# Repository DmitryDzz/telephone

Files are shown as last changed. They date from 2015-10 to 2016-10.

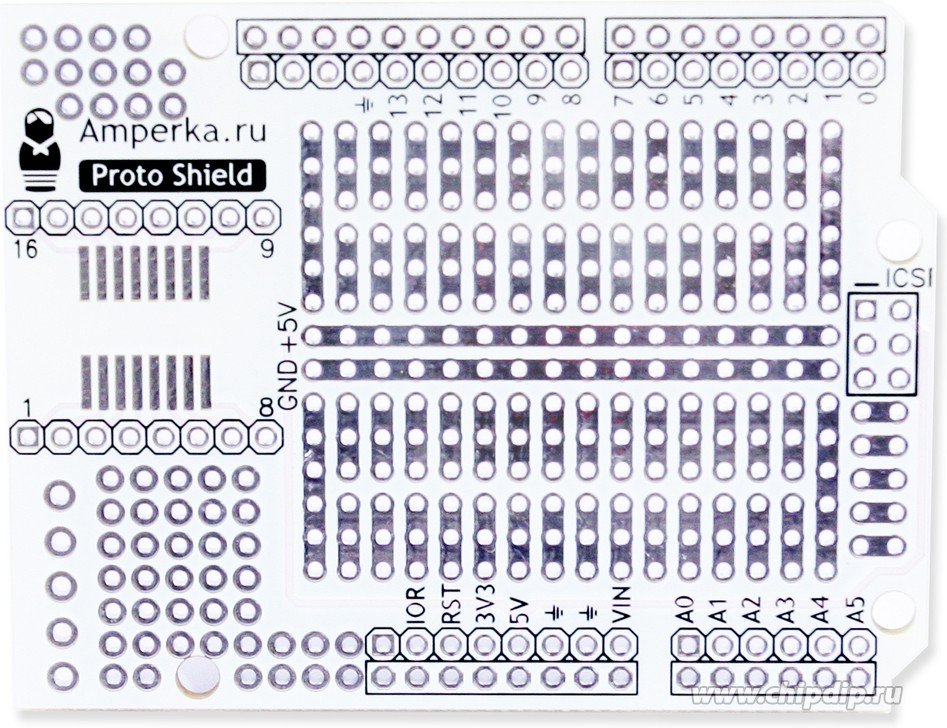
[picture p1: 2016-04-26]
documents/proto-shield.jpg

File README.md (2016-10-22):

# Arduino based cell phone

Arduino based cell phone

Old rotary telephone in modern mobile world. With:
* Arduino UNO controller
* GSM shield
* rechargeable batteries.

To make the phone special I saved its original sound. I mean the sound of its bell set, carbon microphone and rotary dial mechanism.

My detailed instructable [is here](http://www.instructables.com/id/Cell-Phone-With-Bells-AKA-OrPhone/).

Arduino based cell phone

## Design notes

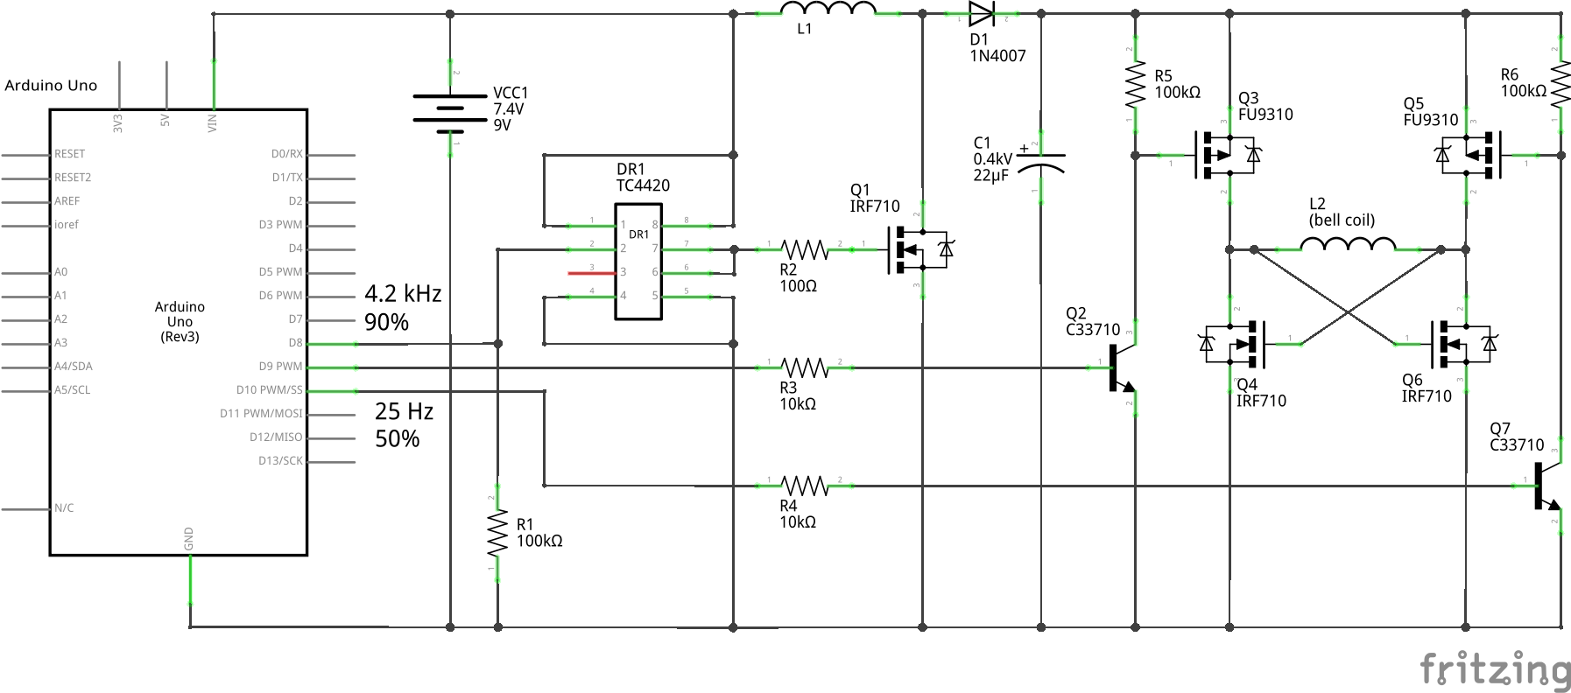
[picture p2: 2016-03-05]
documents/booster/bell-booster-schem.png

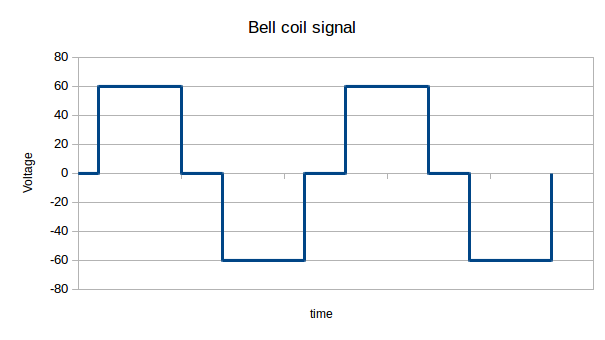
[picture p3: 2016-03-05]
documents/booster/bell-coil-signal.png

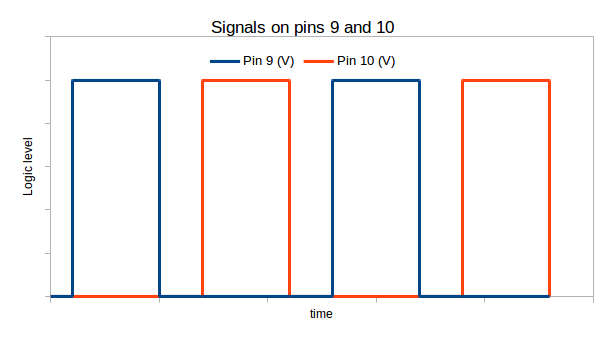
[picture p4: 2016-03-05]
documents/booster/bell-sound-pins-signals.png

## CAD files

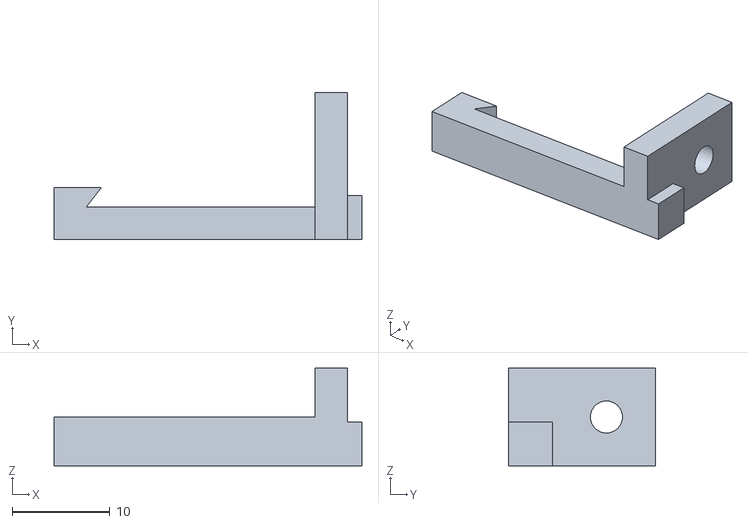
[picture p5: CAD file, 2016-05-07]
3d-printer/antenna-holder.stl
31.5 x 15.0 x 10.0

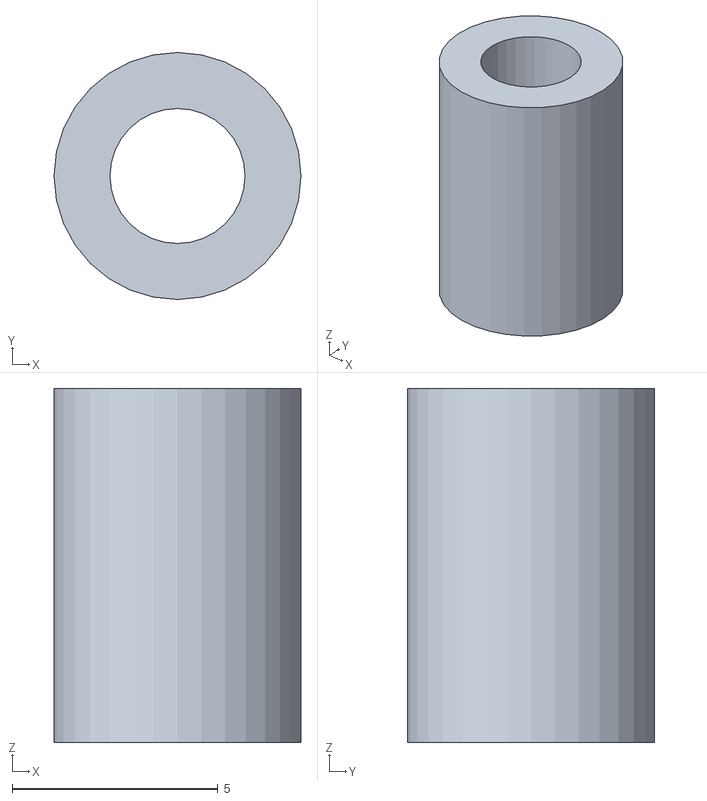
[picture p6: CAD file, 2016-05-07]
3d-printer/arduino-uno-holder.stl
6.00 x 6.00 x 8.60

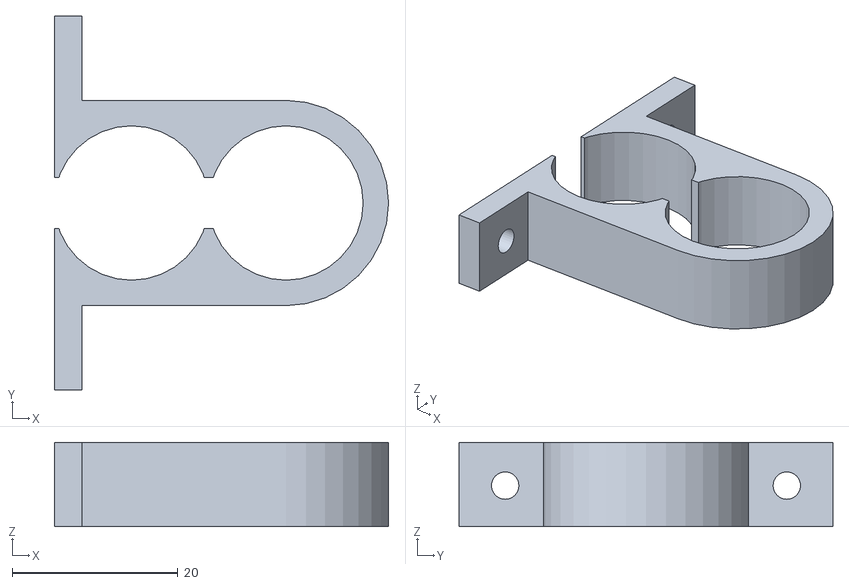
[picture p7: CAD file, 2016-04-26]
3d-printer/battery-18650-holder.stl
40.3 x 45.1 x 10.2

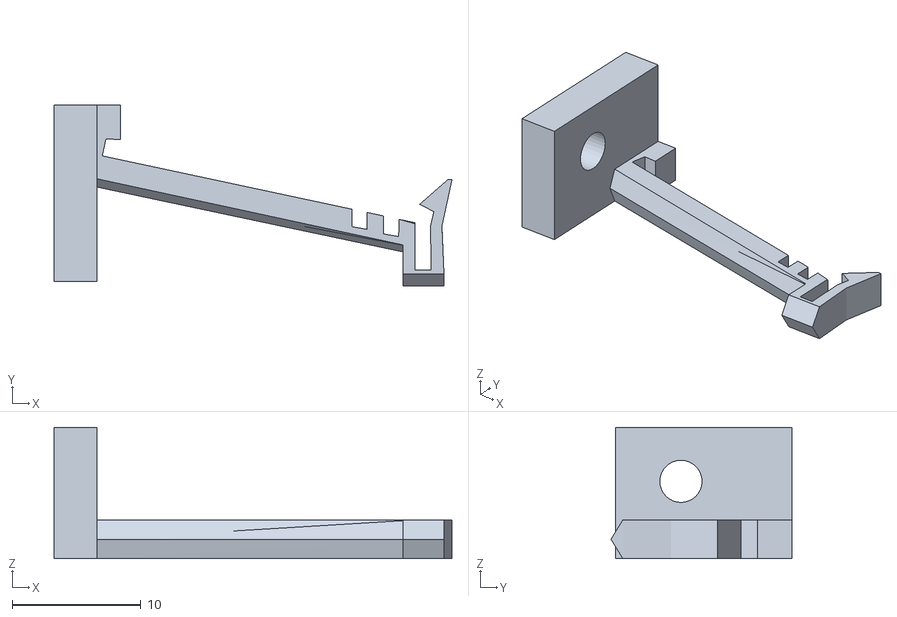
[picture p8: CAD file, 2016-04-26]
3d-printer/charger-holder.stl
30.9 x 14.1 x 10.2

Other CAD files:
3d-printer/antenna-holder.blend
3d-printer/arduino-uno-holder.blend
3d-printer/battery-18650-holder.blend
3d-printer/charger-holder.blend

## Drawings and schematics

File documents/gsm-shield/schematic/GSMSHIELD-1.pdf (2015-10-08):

PWM1 | 35 PWM2 | 36 SDA | 37 SCL | 38 GND | 39 GPIO1/KBR4 | 40 GPIO2/KBR3 | 41 GPIO3/KBR2 | 42 GPIO4/KBR1 | 43 GPIO5/KBR0 | 44 GND | 45 GND | 46 GPIO6/KBC4 | 47 GPIO7/KBC3 | 48 GPIO8/KBC2 | 49 GPIO9/KBC1 | 50 GPIO10 | 51 NETLIGHT

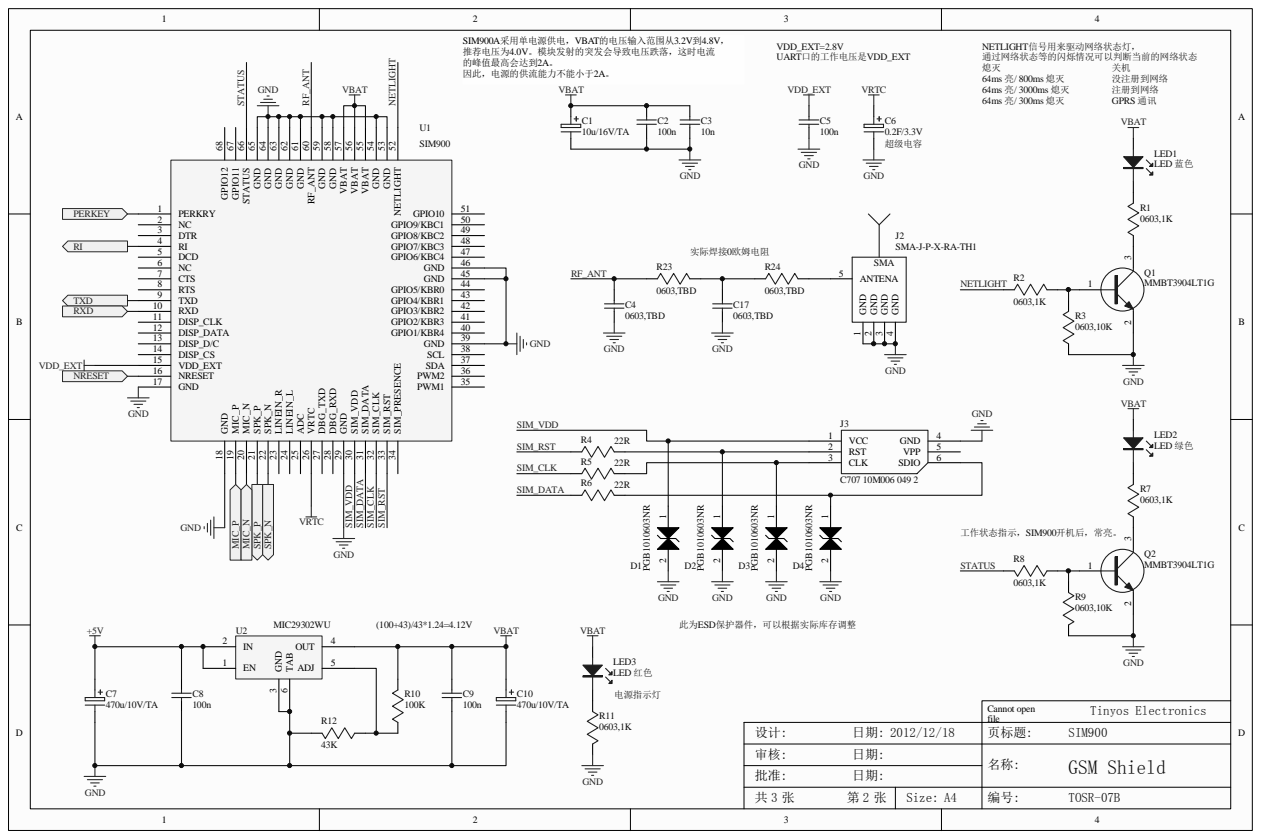
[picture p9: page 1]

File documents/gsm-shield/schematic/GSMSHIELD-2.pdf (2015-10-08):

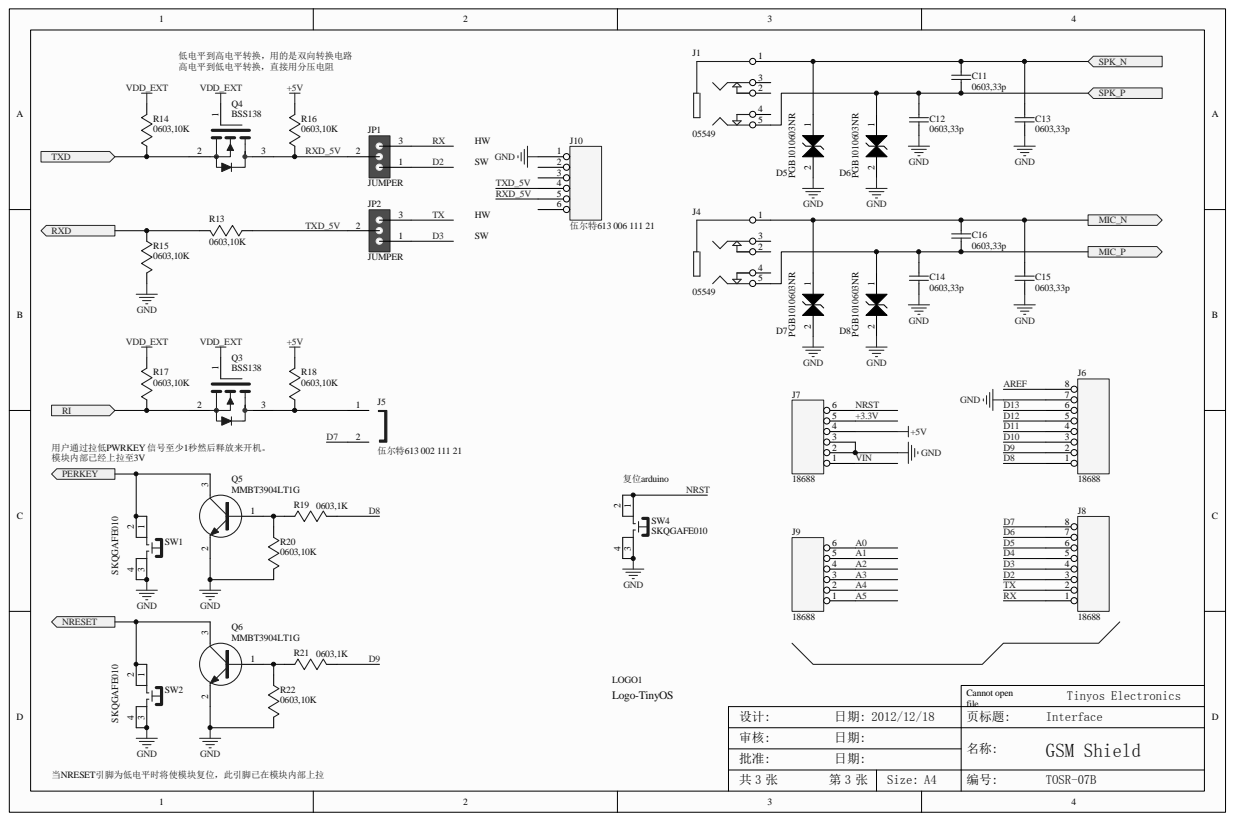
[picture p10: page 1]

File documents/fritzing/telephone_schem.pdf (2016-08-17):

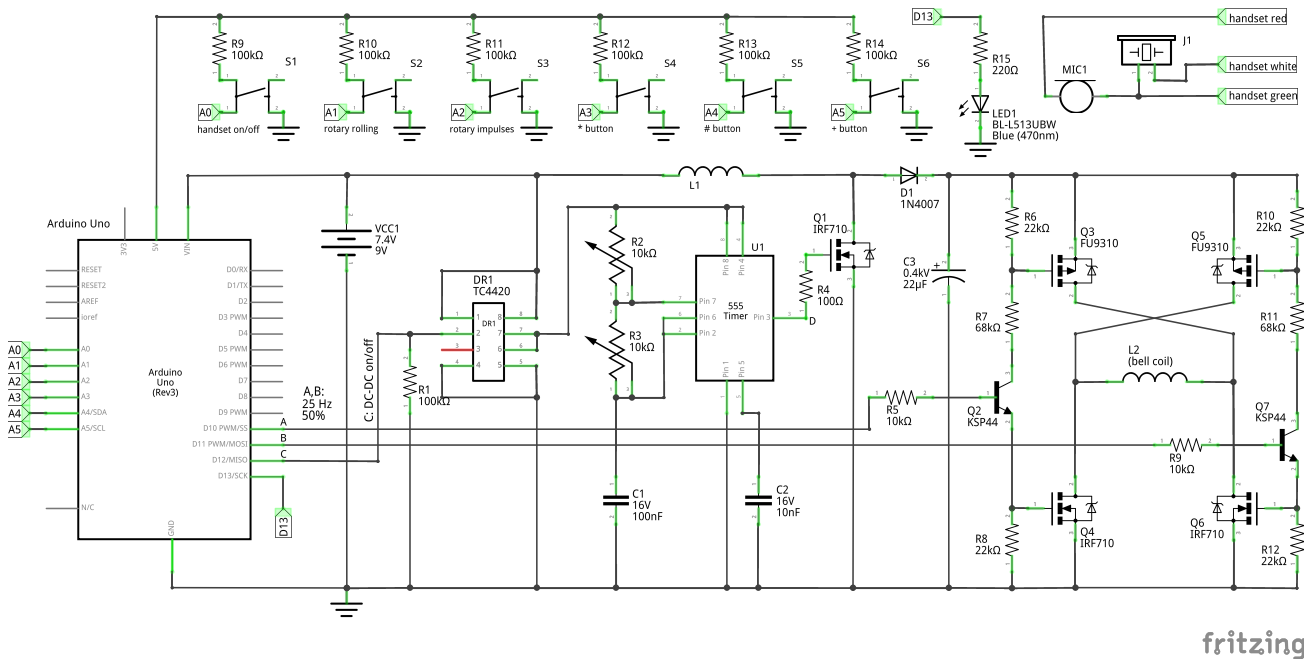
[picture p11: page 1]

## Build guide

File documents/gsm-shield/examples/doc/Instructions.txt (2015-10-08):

***************************************************
GSM/GPRS/GPS Shield of Futura/Open-electronics

http://www.open-electronics.org/

http://store.open-electronics.org/index.php?route=common/home

***************************************************

***************************************************
For support use the issues' page on google code:

http://code.google.com/p/gsm-shield-arduino/issues/

or Arduino Forum

***************************************************

***************************************************
Library created by:

Marco Martines

martines[ dot ]marco[ at ]gmail[ dot ]com
***************************************************

[1] 	How to switch between Arduino Mega and Arduino Uno?
	
	1)
	Open GSM.h and comment-decomment the appropriate lines like below
	e.g. for Arduino Mega
	//#define UNO
	#define MEGA
	
	2)
	If you use Arduino Uno comment the line in HWSerial.h or decomment if
	you are using Arduino Mega
	e.g. for Arduino Mega
	#define MEGA

	3)
	Save and compile

[2]	How to switch between the old shield (that uses 4 and 5 pins for
	SoftwareSerial and the new (that used 2 and 3 pins)?

	1)
	Open GSM.cpp and comment-decomment the appropriate lines like below
	e.g. for the new one

	//#define _GSM_TXPIN_ 4
	//#define _GSM_RXPIN_ 5
	#define _GSM_TXPIN_ 2
	#define _GSM_RXPIN_ 3
	
	2)
	Save and compile

[3]	My shield doesn't work. Why?
	
	Check this steps and then ask for support on the issues' page on google
	code.

	1) 	SIM900 and SIM908 require about 1 A during the hardest tasks.
		You should have an external power source that can provide about
		1 A at 8-12 V

	2)	If the SIM90X blinks (1 Hz) for some seconds and then turn off,
		probably it's a communication's problem. Check the switch/jumpers
		for Serial communication.

	3)	Arduino Uno has 2 KB of RAM. Library takes about 80% (we are working
		to reduce it), if you use more than 20% left, Arduino can restart
		or print on serial strange strings.

	4)	Check the jumper of communication, power source (battery or externel) and charge.

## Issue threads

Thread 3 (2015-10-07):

How to turn on modem on GSM shield automatically?

DmitryDzz, 2015-10-07:
```c
pinMode(8, OUTPUT);
digitalWrite(8, HIGH);
```
in `setup()` doesn't help when USB wire is not connected. I think there's not enough power.

DmitryDzz, 2015-10-11:
Yes, everything's ok with 12V 5A power source.

Closed 2015-10-11.

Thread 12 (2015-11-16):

Make ringing test-sketch

DmitryDzz, 2015-11-16:
Schematic:
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

Arduino Uno is used as a square wave generator.

**Pin 8** — high frequency signal for voltage booster. The signal depends on L1 inductor. The goal is to boost 7.4 DC volts up to 60–80 AC volts on L2 load (bell coil). My L1 inductor has R29.5×19×14.9 ferrite toroid core (B64290-L647-X87, N87) with 450 turns on 0.5 mm enameled copper wire. The maximum voltage on the load was at 4.2 kHz and 89.6% duty cycle.

**Pin 9** and **pin 10** — 25 Hz, 50% duty cycle signal for sound modulation.

Logic zero on pins 8, 9 and 10 stops high voltage generation and sound modulation. Logic 1 on both pins 9 and 10 simultaneously is **not allowed**. The signals on pin 9 and 10 are synchronized and illustrated below:
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

Based on these signals on pins 9 and 10 the final signal on the bell coil (L2) looks something like a sine wave:
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

DmitryDzz, 2015-12-07:
There's more information on [my blog](http://dmitrydzz-hobby.blogspot.ru/2015/11/more-volts.html).

Closed 2016-03-08.

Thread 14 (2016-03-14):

Use asynchronous GSM methods

DmitryDzz, 2016-03-14:
Bell ringing is stuttering – there's a lag in loop() function caused by gsmVoiceCall.getvoiceCallStatus() method. To fix it I should use asynchronous method call instead of default synchronous.

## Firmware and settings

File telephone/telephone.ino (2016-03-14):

#include "button.h"
#include "bell.h"
#include <GSM.h>

using namespace telephone;

const int HEADSET_PIN = A0;
const int ROTATE_PIN = A1;
const int COUNTER_PIN = A2;
const int ASTERISK_PIN = A3;
const int NUMBER_SIGN_PIN = A4;
const int PLUS_PIN = A5;
const int NO_NETWORK_LED_PIN = 13;
const int AUTO_START_GSM_PIN = 8;
const int RESET_GSM_PIN = 9;
const int BELL_HIGH_FREQUENCY_ACTIVITY_PIN = 12;
const int BELL_LOW_FREQUENCY_A_PIN = 10;
const int BELL_LOW_FREQUENCY_B_PIN = 11;


Button buttonHeadset(0, 1023);
Button buttonRotate(0, 1023);
Button buttonCounter(0, 1023);
Button buttonAsterisk(0, 1023);
Button buttonNumberSign(0, 1023);
Button buttonPlus(0, 1023);
Button incomingCall(false, true);

boolean isHeadsetUp;
boolean isGettingDigit;
boolean isTalking;
boolean hasIncomingCall;

int digitValue;
String phoneNumber;

char phoneNumberChars[20]; // 20 - "big" number. Greater than any pnone number.

#define SIM_PIN_NUMBER ""
GSM gsmAccess;
GSMVoiceCall gsmVoiceCall;

void pickedUpHandler(telephone::ButtonState buttonState) {
  isHeadsetUp = buttonState == PRESSED;
  if (isHeadsetUp) {
    if (!isTalking) {
      debugPrintln("Headset up");
      phoneNumber = "";
      if (hasIncomingCall) {
        debugPrintln("Stop ringing");
        Bell::stop();
        if (gsmVoiceCall.answerCall()) {
          isTalking = true;
          while (isTalking && (gsmVoiceCall.getvoiceCallStatus() == TALKING)) {
            refreshButtons(millis());
          }
          isTalking = false;
          gsmVoiceCall.hangCall();
        }
      }
    }
  } else {
    debugPrintln("Headset down");
    isGettingDigit = false;
    if (isTalking) {
      isTalking = false;
    }
  }
}

void rotatingHandler(telephone::ButtonState buttonState) {
  if (isHeadsetUp) {
    isGettingDigit = buttonState == PRESSED;
    if (isGettingDigit) {
      digitValue = 0;
    } else {
      if (digitValue > 0) {
        if (digitValue == 10) {
          digitValue = 0;
        }
        phoneNumber += String(digitValue);
        digitValue = 0;
      }
      if (isTalking) {
        sendDigit();
      } else if (isValidPhoneNumber()) {
        makeCall();
      }
    }
  }
}

void rotaryCounterHandler(telephone::ButtonState buttonState) {
  if (isGettingDigit && (buttonState == RELEASED)) {
    digitValue++;
  }
}

void asteriskHandler(telephone::ButtonState buttonState) {
  if (buttonState == PRESSED) {
    debugPrintln("Asterisk pressed");
    addSymbolToPhoneNumber("*");
  }
}

void numberSignHandler(telephone::ButtonState buttonState) {
  if (buttonState == PRESSED) {
    debugPrintln("Number sign pressed");
    addSymbolToPhoneNumber("#");
  }
}

void plusHandler(telephone::ButtonState buttonState) {
  if (buttonState == PRESSED) {
    debugPrintln("Plus pressed");
    addSymbolToPhoneNumber("+");
  }
}

void addSymbolToPhoneNumber(String symbol) {
  if (isHeadsetUp && (!isGettingDigit)) {
    phoneNumber += symbol;
    if (isTalking) {
        sendDigit();
    }
  }
}

void incomingCallHandler(telephone::ButtonState buttonState) {
  if (buttonState == PRESSED) {
    if (!isHeadsetUp) {
      hasIncomingCall = true;
      debugPrintln("Start ringing");
      Bell::start();
      gsmVoiceCall.retrieveCallingNumber(phoneNumberChars, 20);
      debugPrint("Incoming call: <");
      debugPrint(phoneNumberChars);
      debugPrintln(">");
    }
  } else {
    if (hasIncomingCall) {
      hasIncomingCall = false;
      debugPrintln("Stop ringing");
      Bell::stop();
    }
  }
}

// Adaptered for Russian Beeline operator.
// Modify this function for your country or operator.
boolean isValidPhoneNumber() {
  int phoneNumberSize = phoneNumber.length();
  if (phoneNumberSize == 4) { // Russian Beeline mobile operator short number: 06XX
    return (phoneNumber[0] == '0') && (phoneNumber[1] == '6');
  } else if (phoneNumberSize == 11) { // 8xxxxxxxxxx
    return phoneNumber[0] == '8';
  } else if (phoneNumberSize == 12) { // +7XXXxxxxxxx call to Russia
    return (phoneNumber[0] == '+') && (phoneNumber[1] == '7');
  } else {
    return false;
  }
}

void makeCall() {
  if (isTalking) {
    return;
  }
  debugPrintln("Making call: " + phoneNumber);
  updatePhoneNumberForRussia();
  phoneNumber.toCharArray(phoneNumberChars, phoneNumber.length() + 1);
  phoneNumber = "";
  if (gsmVoiceCall.voiceCall(phoneNumberChars)) {
    isTalking = true;
    while (isTalking && (gsmVoiceCall.getvoiceCallStatus() == TALKING)) {
      refreshButtons(millis());
    }
    isTalking = false;
    gsmVoiceCall.hangCall();
    // ПРОВЕРИТЬ: когда занято.
  }
}

void sendDigit() {
  if (gsmVoiceCall.getvoiceCallStatus() != TALKING) {
    return;
  }
  if (phoneNumber == "") {
    return;
  }

  String atCommand = "AT+VTS=\"" + phoneNumber + "\"";
  debugPrintln("Sending digit: " + phoneNumber + " at command: " + atCommand);

  theGSM3ShieldV1ModemCore.println(atCommand);
  
  phoneNumber = "";
}

void updatePhoneNumberForRussia() {
  if (phoneNumber[0] == '8') {
    phoneNumber[0] = '7';
    phoneNumber = "+" + phoneNumber;
  }
}

void refreshButtons(long currentMillis) {
  buttonHeadset.refresh(analogRead(HEADSET_PIN), currentMillis);
  buttonRotate.refresh(analogRead(ROTATE_PIN), currentMillis);
  buttonCounter.refresh(analogRead(COUNTER_PIN), currentMillis);
  buttonAsterisk.refresh(analogRead(ASTERISK_PIN), currentMillis);
  buttonNumberSign.refresh(analogRead(NUMBER_SIGN_PIN), currentMillis);
  buttonPlus.refresh(analogRead(PLUS_PIN), currentMillis);
  incomingCall.refresh(gsmVoiceCall.getvoiceCallStatus() == RECEIVINGCALL, currentMillis);
}

void debugPrint(String text) {
  Serial.print(text);
}

void debugPrintln(String text) {
  Serial.println(text);
}

void setup() {
  Serial.begin(9600);

  debugPrintln("");
  debugPrintln("Started");

  Bell::initialize(BELL_HIGH_FREQUENCY_ACTIVITY_PIN, BELL_LOW_FREQUENCY_A_PIN, BELL_LOW_FREQUENCY_B_PIN);
  
  pinMode(HEADSET_PIN, INPUT);
  pinMode(ROTATE_PIN, INPUT);
  pinMode(COUNTER_PIN, INPUT);
  pinMode(ASTERISK_PIN, INPUT);
  pinMode(NUMBER_SIGN_PIN, INPUT);
  pinMode(PLUS_PIN, INPUT);
  pinMode(NO_NETWORK_LED_PIN, OUTPUT);
  pinMode(AUTO_START_GSM_PIN, OUTPUT);
  pinMode(RESET_GSM_PIN, OUTPUT);
  delay(100);
  
  digitalWrite(NO_NETWORK_LED_PIN, HIGH);

  // Magic spell to start GSM module automatically:
  digitalWrite(AUTO_START_GSM_PIN, HIGH);
  delay(1000);
  digitalWrite(AUTO_START_GSM_PIN, LOW);
  delay(3000);
  digitalWrite(RESET_GSM_PIN, HIGH);
  delay(1000);
  digitalWrite(RESET_GSM_PIN, LOW);

  buttonHeadset.setHandler(pickedUpHandler);
  buttonRotate.setHandler(rotatingHandler);
  buttonCounter.setHandler(rotaryCounterHandler);
  buttonAsterisk.setHandler(asteriskHandler);
  buttonNumberSign.setHandler(numberSignHandler);
  buttonPlus.setHandler(plusHandler);
  incomingCall.setHandler(incomingCallHandler);
  
  debugPrint("Connecting..");
  while (true) {
    debugPrint(".");
    if (gsmAccess.begin(SIM_PIN_NUMBER) == GSM_READY) {
      debugPrintln("done");
      break;
    }
    delay(1000);
  }
  digitalWrite(NO_NETWORK_LED_PIN, LOW);

  // This makes sure the modem correctly reports incoming events:
  gsmVoiceCall.hangCall();
}

void loop() {
  refreshButtons(millis());
}

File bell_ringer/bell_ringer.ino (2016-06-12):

#include "bell.h"

const int HIGH_FREQUENCY_PIN = 12;
const int LOW_FREQUENCY_A_PIN = 10;
const int LOW_FREQUENCY_B_PIN = 11;
const long DURATION = 1L * 60L * 1000L;
bool started;
long startMillis;

void setup() {
  Serial.begin(9600);
  Serial.println("\n\r");

  Bell::initialize(HIGH_FREQUENCY_PIN, LOW_FREQUENCY_A_PIN, LOW_FREQUENCY_B_PIN);

  Bell::start();
  started = true;
  startMillis = millis();
  Serial.print("Started...");
}

void loop() {
//  delay(1000);
//  Serial.println("Hi!");
  if (started && (millis() - startMillis >= DURATION)) {
    Bell::stop();
    started = false;
    Serial.println("stopped");
  }
}

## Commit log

2015-09-28 Resolved #1 Button class
    [telephone.ino]
2015-09-28 Resolved #2 rotary dial input
    [telephone.ino]
2015-10-11 #4 short phone numbers and tone commands
    [telephone.ino]
2015-10-11 Resolved #4 making calls
    [telephone.ino]
2015-10-11 Resolved #5 DTFM - sending commands in voice call
    [telephone.ino]
2015-10-11 Resolved #6 common gnd
2015-10-11 Resolved #7 asterisk, number sign and plus are handled now
    [telephone.ino]
2015-10-13 Resolved #8 voice call receiving
    [telephone.ino]
2015-10-13 Resolved #9 network connection LED
    [telephone.ino]
2015-12-07 #12 new booster in fritzing plus new booster test sketch - born of hope
    [booster.fzz]
2015-12-07 #12 fixed booster.fzz
    [booster.fzz]
2015-12-09 #12 booster.fzz - NPN was changed to MOSFET
    [booster.fzz]
2015-12-12 #12 second N-channel MOSFET is bad idea
    [booster.fzz]
2015-12-19 #12 new version with MOSFET-drivers
    [booster-driver.fzz, booster-mosfet.fzz, booster.fzz]
2016-03-03 #12 Frequency fix for 48 volts output
    [booster-with-gen.fzz]
2016-03-05 #12 Full schematic of bell booster: bell-booster.fzz
    [bell-booster.fzz]
2016-03-05 Resolved #12 Bell booster
    [bell-booster.fzz, charts.ods]
2016-03-08 Resolved #12 More powerful NPN transistors
    [bell-booster.fzz, booster-driver.fzz, booster-mosfet.fzz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]
2016-03-11 #13 New sketch and fzz bell_ringer
    [bell-ringer.fzz]
2016-03-11 #13 New bell-ringer sketch and fzz with 555 timer high frequency generator
    [bell-ringer.fzz]
2016-03-11 #13 Removed deprecated files
    [bell-booster.fzz]
2016-03-14 Resolved #13 Final sketch
    [bell.cpp, telephone.ino]
2016-03-19 Resolved #15 Bell ringer pcb
    [bell-ringer.fzz, telephone.fzz]
2016-03-19 Resolved #15 Bell ringer pcb fix
2016-04-26 3D models: battery holder and charger holder
    [battery-18650-holder-2.blend, battery-18650-holder-2.stl, battery-18650-holder-3.blend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]
2016-04-26 Final battery holder and charger holder
    [battery-18650-holder-2.blend, battery-18650-holder-2.stl, battery-18650-holder-3.blend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]
2016-05-07 Arduino Uno and antenna holders
    [antenna-holder.blend, antenna-holder.stl, arduino-uno-holder.blend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]
2016-06-13 #16 New DC-AC converter schema
    [telephone.fzz]
2016-08-17 #16 DC-AC converter fix: telephone2.fzz
    [telephone.fzz, telephone2.fzz]
2016-08-19 Fixed #16 New DC-AC converter
    [telephone.fzz, telephone2.fzz]
